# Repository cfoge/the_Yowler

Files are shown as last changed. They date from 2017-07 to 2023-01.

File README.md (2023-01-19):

# the_Yowler
If you find this usefull and would like to pay it forward you can do so here 
XXXXXXXXXXXXXXXXXXXXXXXXXXXXXXXX

WARNING!!!!! Please be aware of the risks asociated with electronics and take the relivant percautuions.

XXXXXXXXXXXXXXXXXXXXXXXXXXXXXXXX

An open source noise maker that saw its life as a Kickstarter product in 2017 and has now become open.

[Mouser BOM cart](https://au.mouser.com/ProjectManager/ProjectDetail.aspx?AccessID=0d14517efb)

The design originates from this kickstarter: https://www.kickstarter.com/projects/218568730/the-yowler-a-community-built-diy-noise-synth
and features:
4 square wave oscilators with knobs and switchible ldr's
3 xor gates used to mix the signals
1 primitive vca made from back to back diodes
a rc low pass filter
a decay cap 
trigger button/jack
sterio/mono out
built in speaker

Please use the design files and ideas in this project to make your own stuff, and share your designs and creations with others.
If you come up with any great ideas or mods, please tell me so i can roll good ideas back into the main design.

Cheers

Rob

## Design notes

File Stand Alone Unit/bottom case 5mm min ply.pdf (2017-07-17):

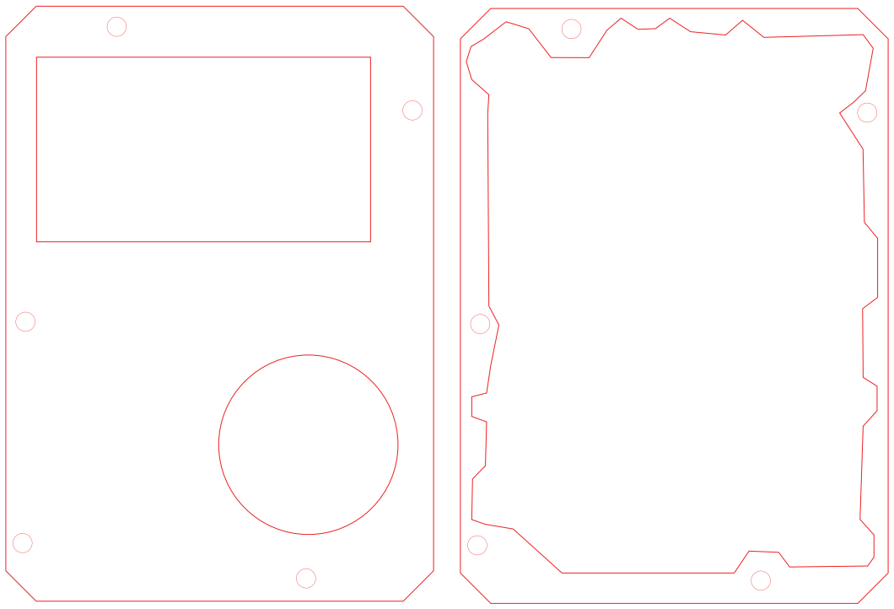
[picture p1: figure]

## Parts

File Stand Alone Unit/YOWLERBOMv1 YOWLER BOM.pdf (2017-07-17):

### YOWLER BOM

Part | VALUE | Number
BAT1 | 9v batery clip | 1
C1 | 100uf POLARIZED CAPACITOR | 1
C2-C6 | 0.1uf | 5
C7 | 4.7uf POLARIZED CAPACITOR < 50v | 1
C8 | 4.7uf POLARIZED CAPACITOR (ELECTROLITIC) <50v | 1
C9 | 47uf Capacitor Polarized <50v | 1
CN1 | 2.0mm DC Barrel Jack | 1
D1 | 1n4001 | 1
D2-D3 | 1N4148 | 2
Dip14 | 14 pin ic socket | 2
IC1 | 40106N Hex SCHMITT TRIGGER | 1
IC2 | 4070N Quad 2-input XOR | 1
LED1-LED2 LED3MM "yellow" | 2
OPH1-OPH4 VT90N1 100k LDR | 4
R1,R5 | 330ohm 1/4w | 2
R2-R4 & R6 10kohm 1/4w | 4
R7 | 100ohm 1/4w | 1
RV1-RV5 | 100k POT "ALPS_POT" | 4
RV5 | 10k log | 1
S1 | SWITCH-MOMENTARY-12MM | 1
SP1 | SPEAKER PCB_MOUNT COM-11089 | 1
SW1 | SW_DIP-6 | 1
SW2 | SW_DIP-4 | 1
T1 | 2N3904 "NPN TRANSISTOR" | 1
U1 | 9v V_REG 7809 | 1
X1-X2 | STEREOJACK STX3100 | 2

OPTINAL:
KNOBS | | 4
BOLTS for case 12mm M3 | 5
NUTS for case M3 | 5

LINK
http://www.altronics.com.au/p/s5048-9v-battery-holder-pcb-mount/

http://www.taydaelectronics.com/dc-power-jack-2-1mm-barrel-type-pcb-mount.htmlhttps://www.taydaelectronics.com/1n4001-diode-1a-50v.htmlhttps://www.taydaelectronics.c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

https://www.taydaelectronics.com/100k-ohm-logarithmic-taper-potentiometer-round-shaft-pcb-9mm.htmlhttps://www.taydaelectronics.com/10k-ohm-logarithmic-taper-potentio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 or try Sparkfun in the US https://www.taydaelectronics.com/dip-switch-6-positions-gold-plated-contacts-side-actuated-piano.htmlhttps://www.taydaelectronics.com/dip-switch-4-positions-gold-pla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

http://www.taydaelectronics.com/kn8f-knob-grey.html

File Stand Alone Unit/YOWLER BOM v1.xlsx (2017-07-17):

YOWLER BOM
Part | VALUE | Number | LINK
BAT1 | 9v batery clip | 1 | http://www.altronics.com.au/p/s5048-9v-battery-holder-pcb-mount/
C1 | 100uf POLARIZED CAPACITOR | 1
C2-C6 | 0.1uf | 5
C7 | 4.7uf POLARIZED CAPACITOR < 50v | 1
C8 | 4.7uf POLARIZED CAPACITOR (ELECTROLITIC) <50v | 1
C9 | 47uf Capacitor Polarized <50v | 1
CN1 | 2.0mm DC Barrel Jack | 1 | http://www.taydaelectronics.com/dc-power-jack-2-1mm-barrel-type-pcb-mount.html
D1 | 1n4001 | 1 | https://www.taydaelectronics.com/1n4001-diode-1a-50v.html
D2-D3 | 1N4148 | 2 | https://www.taydaelectronics.com/1n4148-switching-signal-diode.html
Dip14 | 14 pin ic socket | 2 | https://www.taydaelectronics.com/14-pin-dip-ic-socket-adaptor-solder-type.html
IC1 | 40106N Hex SCHMITT TRIGGER | 1 | https://www.taydaelectronics.com/cd40106-cd40106be-40106-hex-schmitt-trigger-ic.html
IC2 | 4070N Quad 2-input XOR | 1 | https://www.taydaelectronics.com/cd4070-cd4070be-4070-quad-exclusive-or-gate-ic.html
LED1-LED2 | LED3MM "yellow" | 2 | https://www.taydaelectronics.com/led-3mm-yellow.html
OPH1-OPH4 | VT90N1 100k LDR | 4 | http://www.taydaelectronics.com/photo-conductive-cell-resistor-ldr-650nm-radial-ke-10720.html
R1,R5 | 330ohm 1/4w | 2
R2-R4 & R6 | 10kohm 1/4w | 4
R7 | 100ohm 1/4w | 1
RV1-RV5 | 100k POT "ALPS_POT" | 4 | https://www.taydaelectronics.com/100k-ohm-logarithmic-taper-potentiometer-round-shaft-pcb-9mm.html
RV5 | 10k log | 1 | https://www.taydaelectronics.com/10k-ohm-logarithmic-taper-potentiometer-round-knurled-plastic-shaft-pcb-9mm.html
S1 | SWITCH-MOMENTARY-12MM | 1 | http://www.altronics.com.au/p/s1125-spst-momentary-pcb-mount-4.3mm-tactile-switch/
SP1 | SPEAKER PCB_MOUNT COM-11089 | 1 | https://littlebirdelectronics.com.au/products/speaker-pcb-mount | or try Sparkfun in the US
SW1 | SW_DIP-6 | 1 | https://www.taydaelectronics.com/dip-switch-6-positions-gold-plated-contacts-side-actuated-piano.html
SW2 | SW_DIP-4 | 1 | https://www.taydaelectronics.com/dip-switch-4-positions-gold-plated-contacts-side-actuated-piano.html
T1 | 2N3904 "NPN TRANSISTOR" | 1 | https://www.taydaelectronics.com/2n3904-npn-general-propose-transistor.html
U1 | 9v V_REG 7809 | 1 | https://www.taydaelectronics.com/l7809cv-l7809-7809-voltage-regulator-ic-9v-1-5a.html
X1-X2 | STEREOJACK STX3100 | 2 | http://www.digikey.com.au/product-detail/en/cui-inc/SJ1-3555NG-BE/CP1-3555NG-BE-ND/2295995
OPTINAL:
KNOBS |  | 4 | http://www.taydaelectronics.com/kn8f-knob-grey.html
BOLTS for case | 12mm M3 | 5
NUTS for case | M3 | 5

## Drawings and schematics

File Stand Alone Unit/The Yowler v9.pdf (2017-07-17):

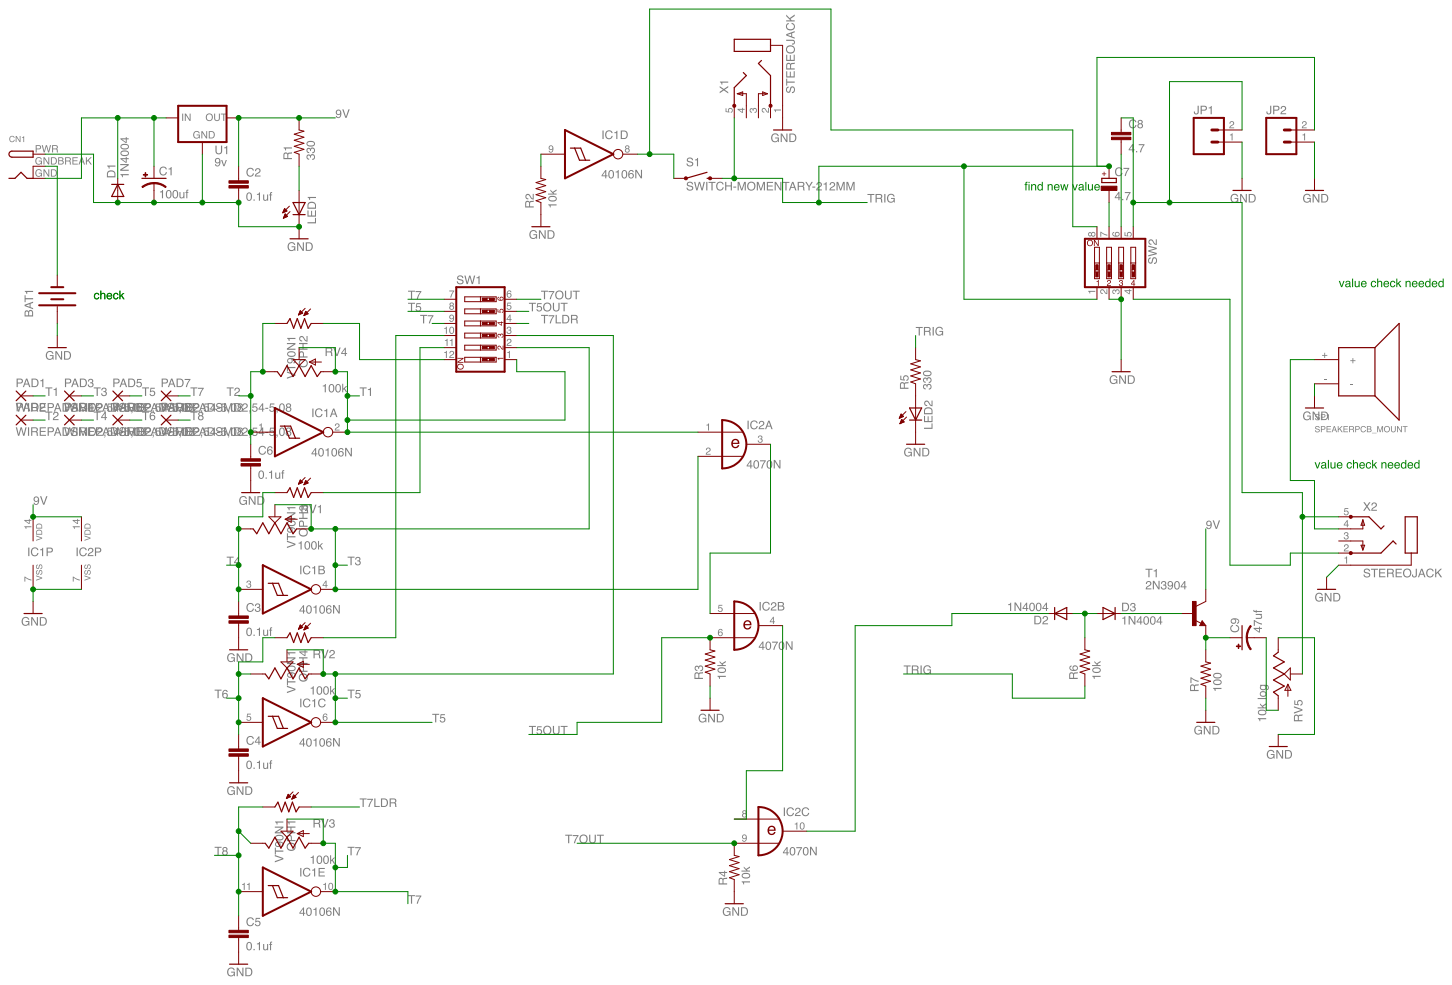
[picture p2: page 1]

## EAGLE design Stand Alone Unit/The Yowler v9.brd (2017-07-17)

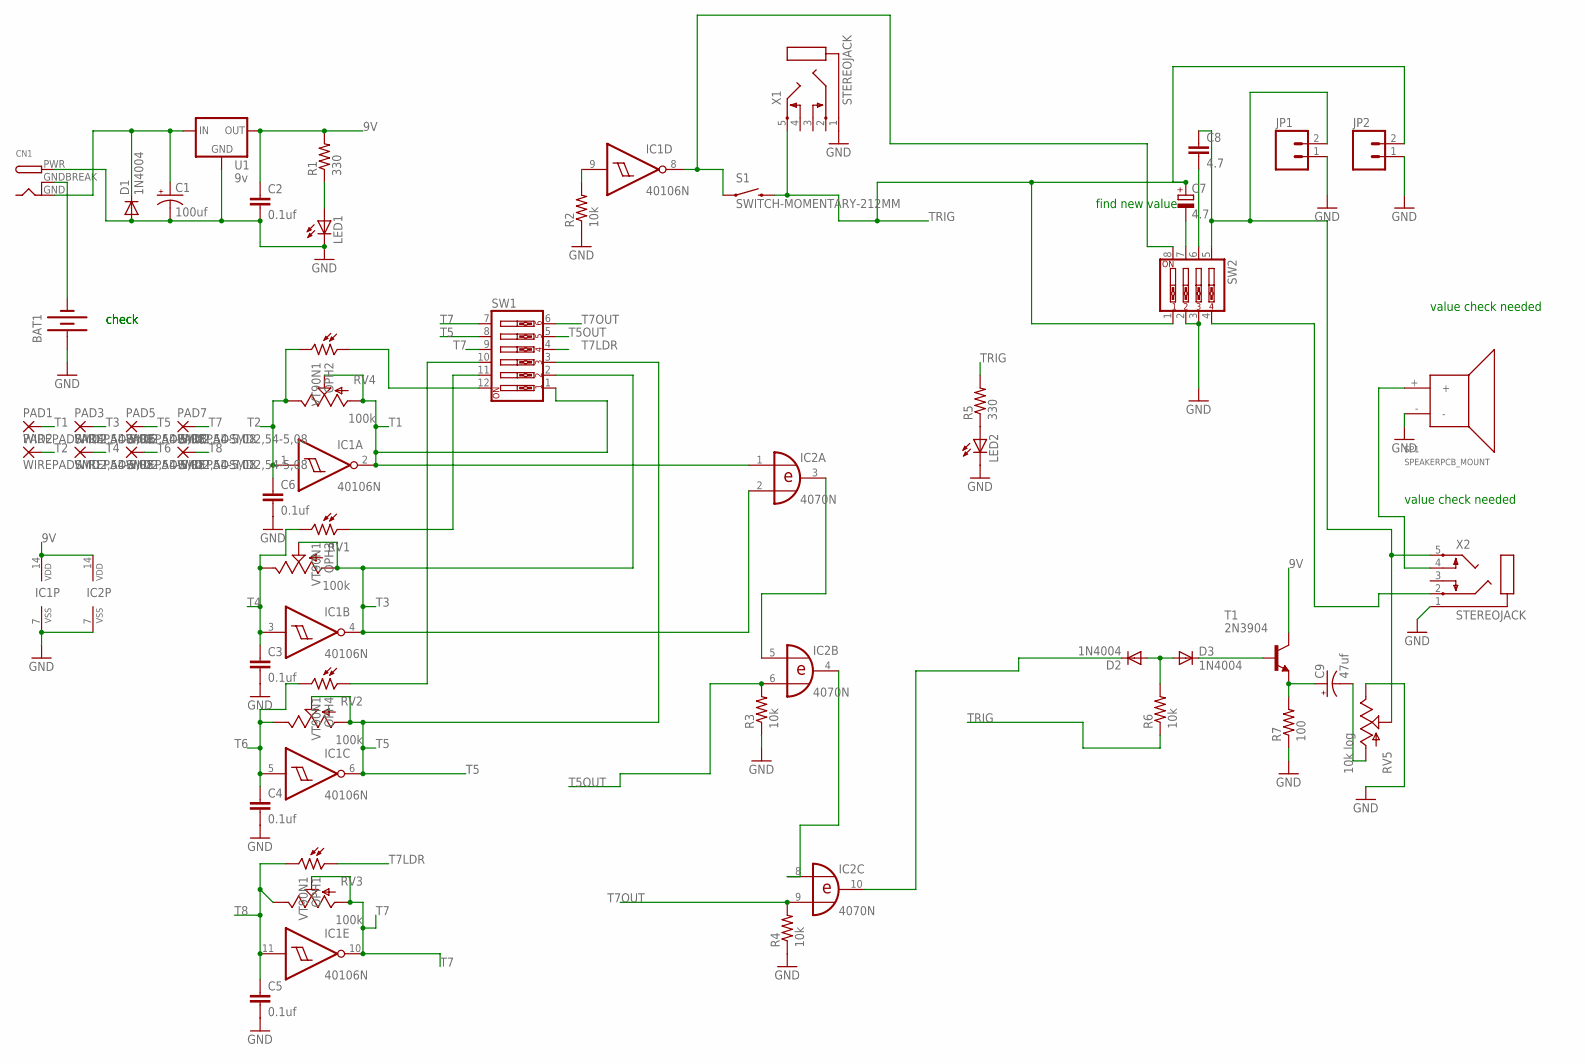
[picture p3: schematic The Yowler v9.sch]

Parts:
BAT1: BATTERY9V; BATTCON_9V
C1: 100uf; E5-6
C2, C3, C4, C5, C6: 0.1uf; CAP-PTH-5MM
C7: 4.7; E5-5
C8: 4.7; C050-030X075
C9: 47uf; CPOL-RADIAL-10UF-25V
CN1: DCBARRELPTH; DCJACK_2MM_PTH
D1, D2, D3: 1N4004; DO41-10
IC1: 40106N; DIL14
IC2: 4070N; DIL14
JP1, JP2: M02POGO_PIN_HOLES_ONLY; 1X02_PP_HOLES_ONLY
LED1, LED2: LED3MM
OPH1, OPH2, OPH3, OPH4: VT90N1; VT900
PAD1, PAD2, PAD3, PAD4, PAD5, PAD6, PAD7, PAD8: WIREPADSMD2,54-5,08; SMD2,54-5,08
R1, R5: 330; AXIAL-0.4
R2, R3, R4, R6: 10k; AXIAL-0.4
R7: 100; AXIAL-0.4
RV1, RV2, RV3, RV4: 100k; ALPS_POT
RV5: 10k log; ALPS_POT
S1: SWITCH-MOMENTARY-212MM; TACTILE-PTH-12MM
SP1: SPEAKERPCB_MOUNT; PCB_MOUNT_SPEAKER
SW1: SW_DIP-6; EDG-06
SW2: SW_DIP-4; EDG-04
T1: 2N3904; TO92
U1: 9v; TO-220-ALT
X1, X2: STEREOJACK; STX3100

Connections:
9V: C2.1, IC1.14 (VDD), IC2.14 (VDD), R1.P$2 (2), T1.1 (C), U1.OUT
AUDIO: SW2.4, X2.2
GND: BAT1.+, C1.-, C2.2, C3.2, C4.2, C5.2, C6.2, CN1.PWR, D1.A, IC1.7 (VSS), IC2.7 (VSS), JP1.1, JP2.1, LED1.K (C), LED2.K (C), R2.P$1 (1), R3.P$1 (1), R4.P$1 (1), R7.P$1 (1), RV5.P$1 (E), SP1.-, SW2.2, SW2.3, U1.GND, X1.1, X2.1
unnamed: LED2.A, R5.P$1 (1)
unnamed: IC1.9 (I), R2.P$2 (2)
unnamed: OPH4.1, SW1.10
unnamed: IC2.4 (O), IC2.8 (I0)
unnamed: C9.2 (-), RV5.P$3 (A)
unnamed: C1.+, CN1.GND, D1.C, U1.IN
unnamed: LED1.A, R1.P$1 (1)
unnamed: IC2.3 (O), IC2.5 (I0)
unnamed: OPH2.1, SW1.12
unnamed: IC1.8 (O), S1.1, SW2.8
unnamed: OPH3.1, SW1.11
unnamed: BAT1.-, CN1.GNDBREAK
unnamed: C8.2, SW2.6
unnamed: D2.C, IC2.10 (O)
unnamed: D2.A, D3.A, R6.P$2 (2)
unnamed: C7.-, SW2.7
unnamed: D3.C, T1.2 (B)
unnamed: C9.1 (+), R7.P$2 (2), T1.3 (E)
unnamed: C8.1, JP1.2, RV5.P$2 (S), SW2.5, X2.5
unnamed: SP1.+, X2.4
T1: IC1.2 (O), IC2.1 (I0), PAD1.1, RV4.P$2 (S), RV4.P$3 (A), SW1.1
T2: C6.1, IC1.1 (I), OPH2.2, PAD2.1, RV4.P$1 (E)
T3: IC1.4 (O), IC2.2 (I1), PAD3.1, RV1.P$2 (S), RV1.P$3 (A), SW1.2
T4: C3.1, IC1.3 (I), OPH3.2, PAD4.1, RV1.P$1 (E)
T5: IC1.6 (O), PAD5.1, RV2.P$2 (S), RV2.P$3 (A), SW1.3, SW1.8
T5OUT: IC2.6 (I1), R3.P$2 (2), SW1.5
T6: C4.1, IC1.5 (I), OPH4.2, PAD6.1, RV2.P$1 (E)
T7: IC1.10 (O), PAD7.1, RV3.P$2 (S), RV3.P$3 (A), SW1.7, SW1.9
T7LDR: OPH1.1, SW1.4
T7OUT: IC2.9 (I1), R4.P$2 (2), SW1.6
T8: C5.1, IC1.11 (I), OPH1.2, PAD8.1, RV3.P$1 (E)
TRIG: C7.+, JP2.2, R5.P$2 (2), R6.P$1 (1), S1.3 (2), SW2.1, X1.5

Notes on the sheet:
check
value check needed
find new value

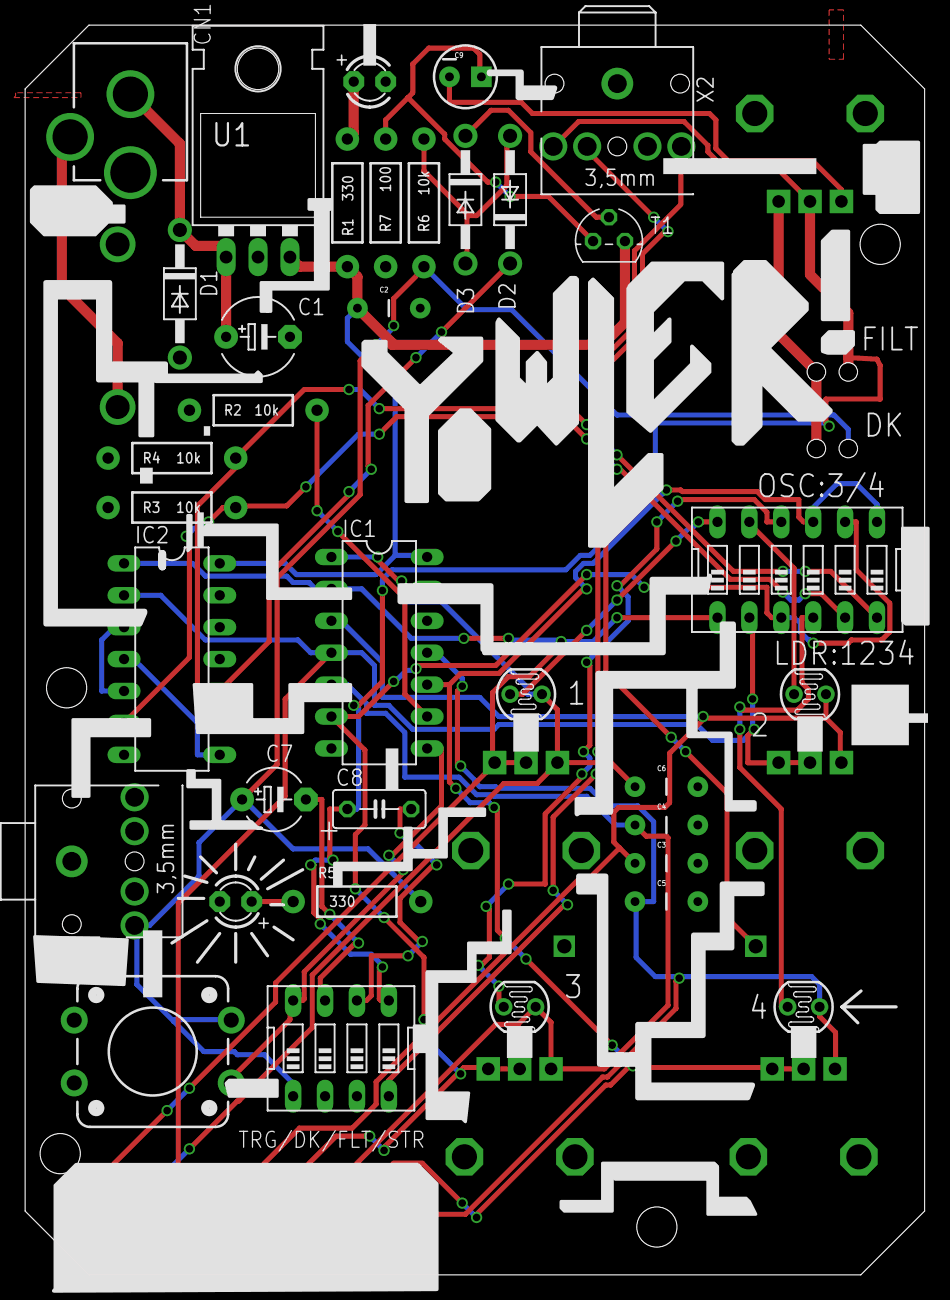
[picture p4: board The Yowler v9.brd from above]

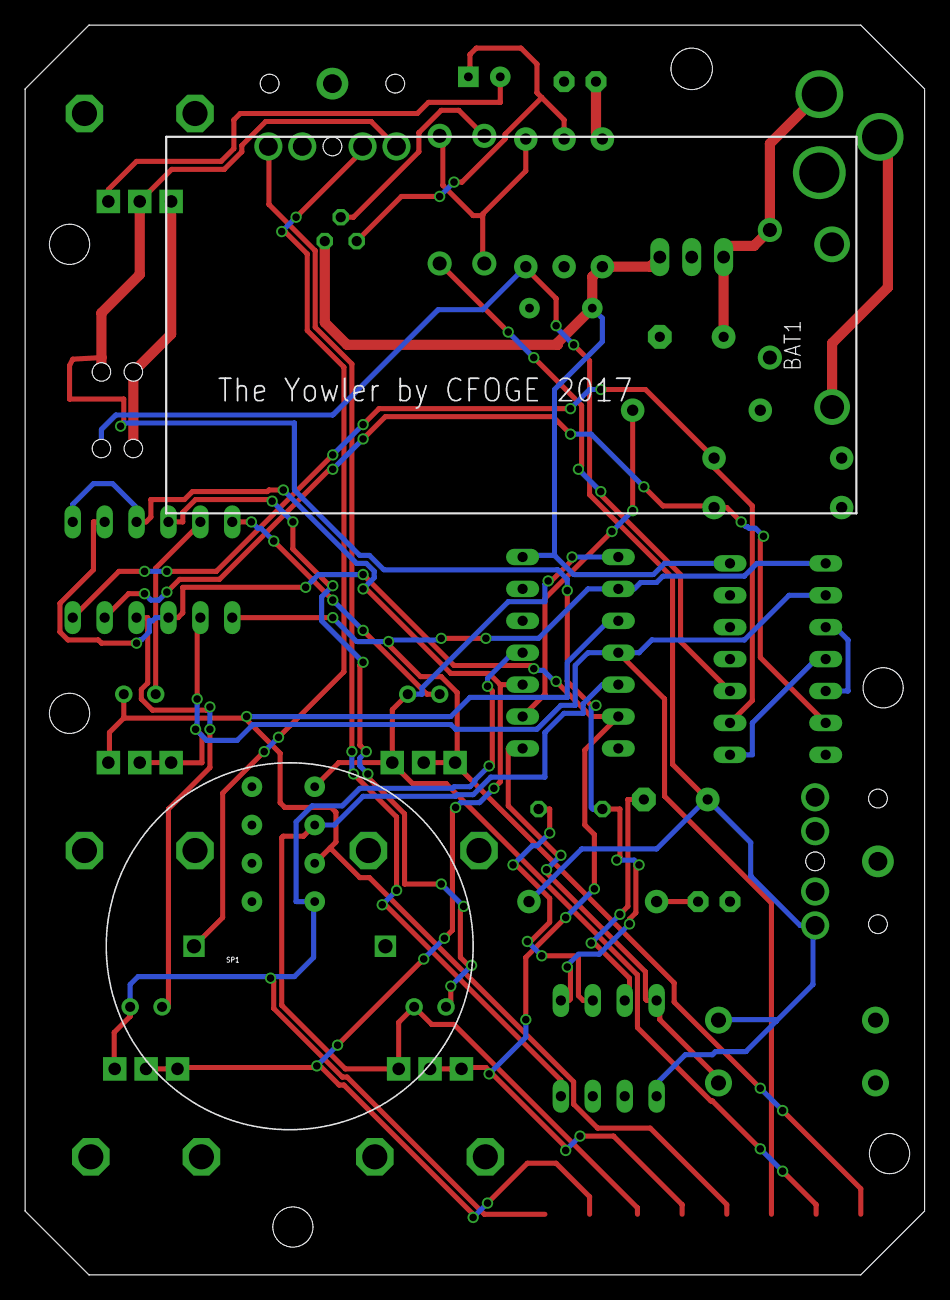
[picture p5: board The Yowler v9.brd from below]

Board: 2 copper layers, 71.6 x 99.5 mm, 52 parts (2 on the bottom side), 35 nets.

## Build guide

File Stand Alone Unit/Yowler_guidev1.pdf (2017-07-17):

9v dc centre negtive

Audio out | Volume

0-5v trigger in
(do not go over 9v!!!)

Trigger buttons

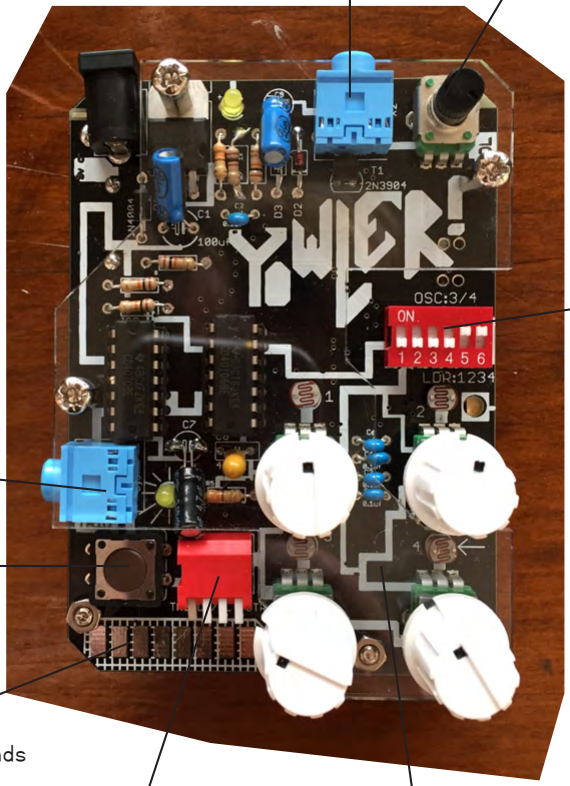
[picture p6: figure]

Glitch touch pads

Oscilator switches:
1.osc1 LDR on/off
2.osc2 LDR on/off
3.osc3 LDR on/off
4.osc4 LDR on/off
5.osc3 on/off
6.osc4 on/off

Pitch knobs for:
osc1 | osc2
osc3 | osc4

Mode switches:
1.trigger on/off
2.triger decay on/off
3.filter on/off
4.mono/sterio output

# Yowler 1page Guide:

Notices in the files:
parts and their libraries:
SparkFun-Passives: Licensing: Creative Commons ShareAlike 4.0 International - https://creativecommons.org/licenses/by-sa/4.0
